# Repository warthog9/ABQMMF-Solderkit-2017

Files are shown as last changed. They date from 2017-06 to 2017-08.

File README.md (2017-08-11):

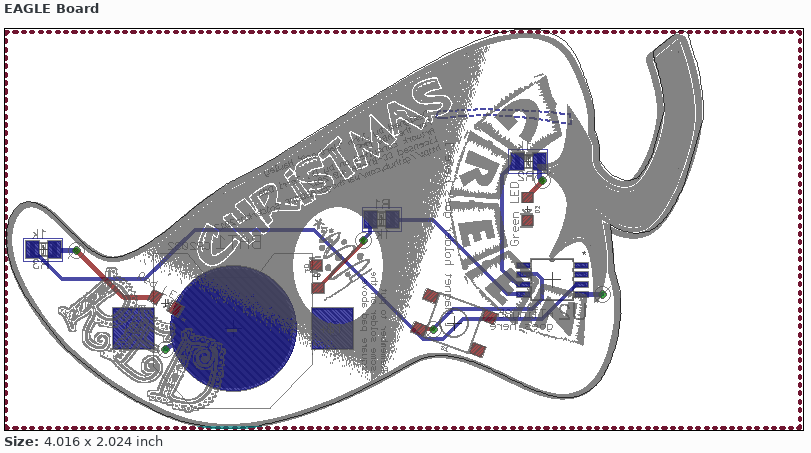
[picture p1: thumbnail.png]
Thumbnail of the Hatch Green Chile Soldering Kit for ABQMMF


This is the learn to solder badge for the Albuquerque Mini Maker Faire.

License:
	The design is opened based on the Creative Commons CC-BY-SA 4.0
	[https://creativecommons.org/licenses/by-sa/4.0/](https://creativecommons.org/licenses/by-sa/4.0/)

	Copyright on the badge is held by John 'Warthog9' Hawley
	
	Copyright to the outline (shape) of the badge is Dr. Terri Oda

	Copyright of the PCBWay Logo is copyright of PCBWay and is used
	with permission specifically for the run of kits used by
	ABQ MMF in 2017

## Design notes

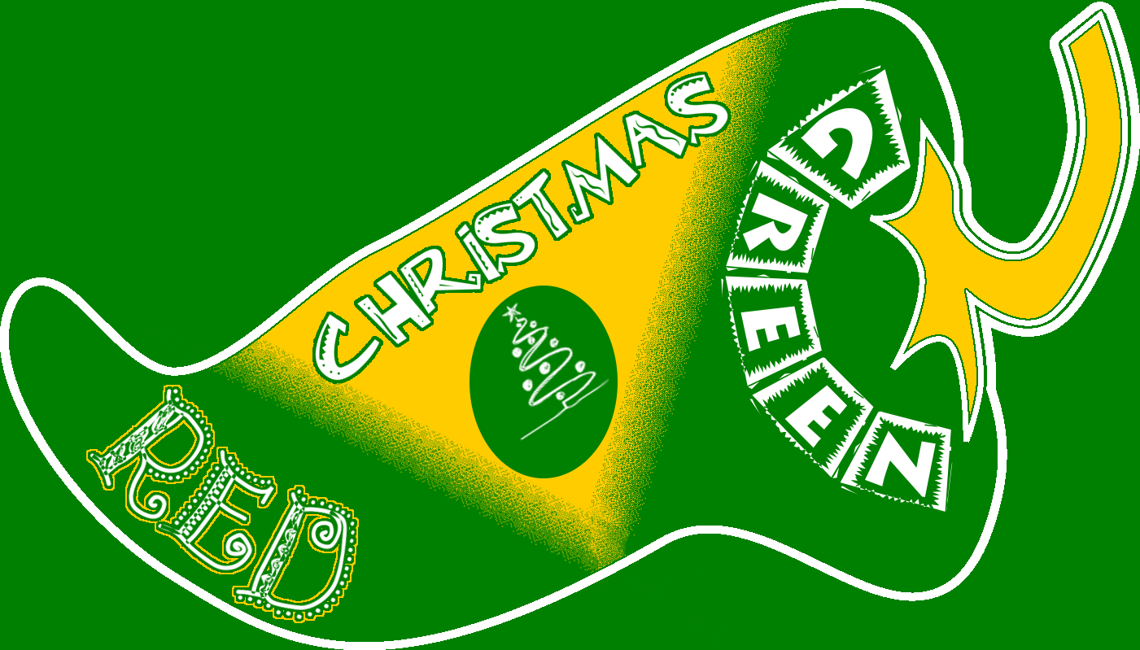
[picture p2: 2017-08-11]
greenchile - w-outline.png

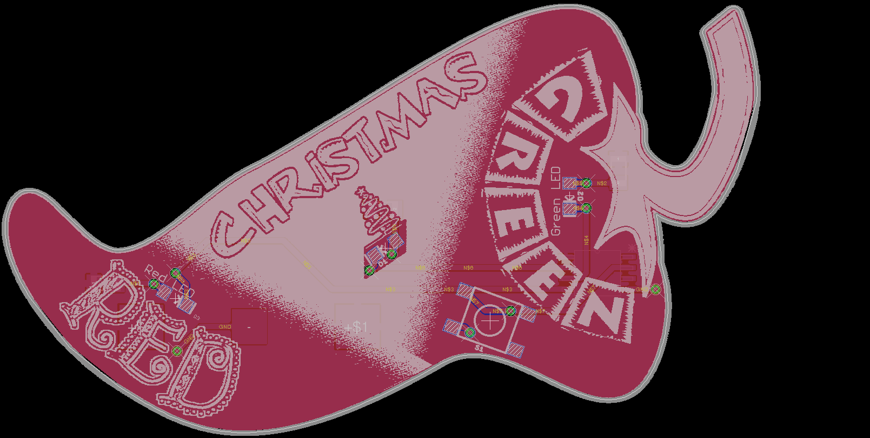
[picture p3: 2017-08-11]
top.png

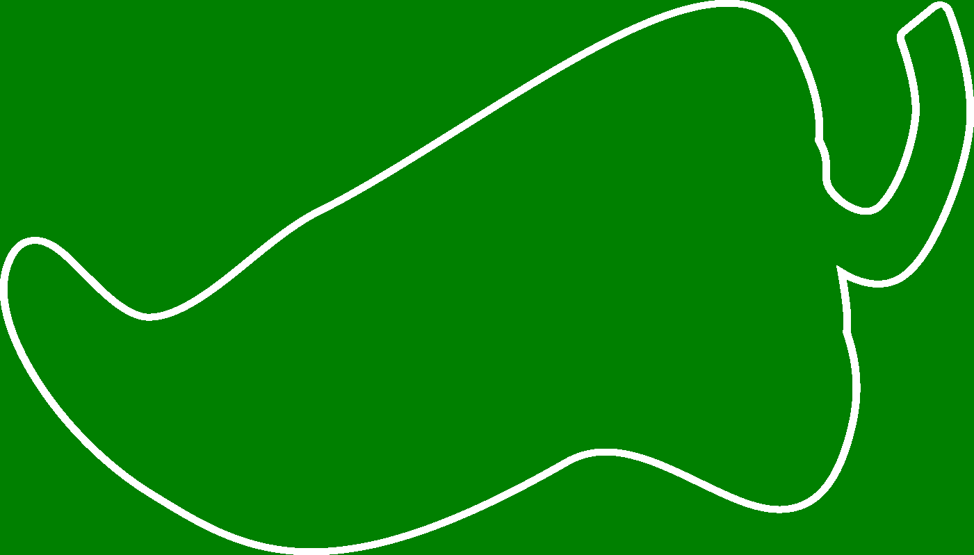
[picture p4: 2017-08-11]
outline.bmp

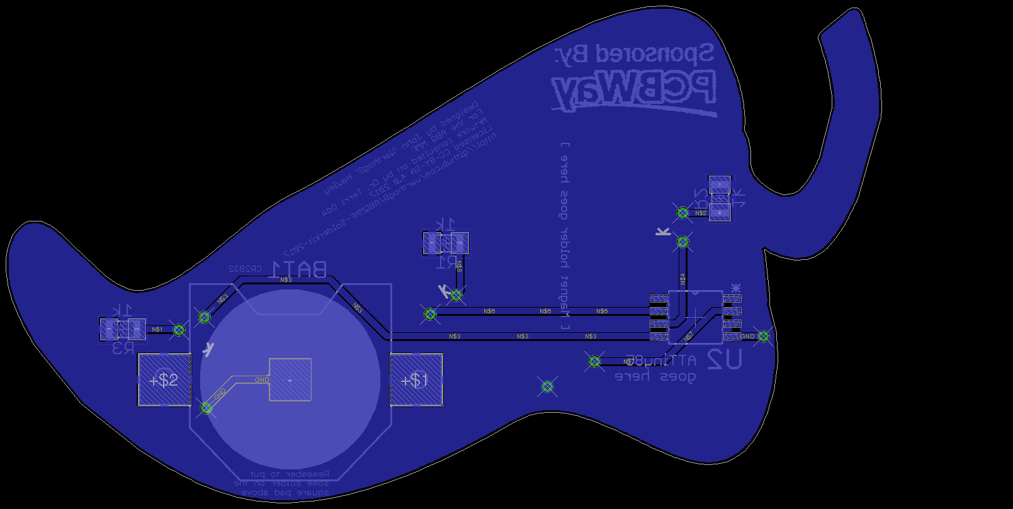
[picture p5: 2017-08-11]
bottom.png

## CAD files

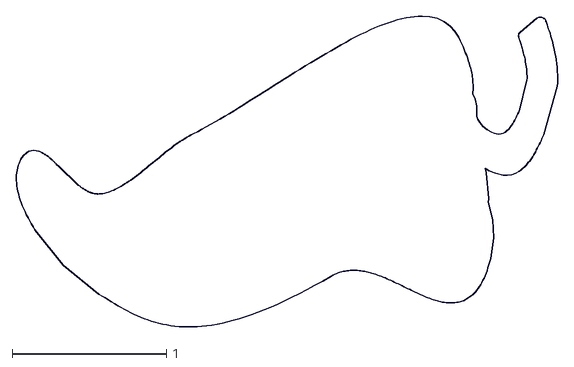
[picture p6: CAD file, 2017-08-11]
greenchile - outline - r9v5.dxf
3.51 x 2.02

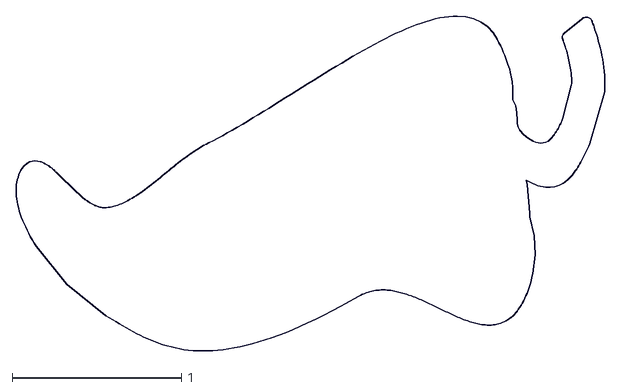
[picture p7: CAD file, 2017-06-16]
greenchile - outline - r9.dxf
3.48 x 1.98

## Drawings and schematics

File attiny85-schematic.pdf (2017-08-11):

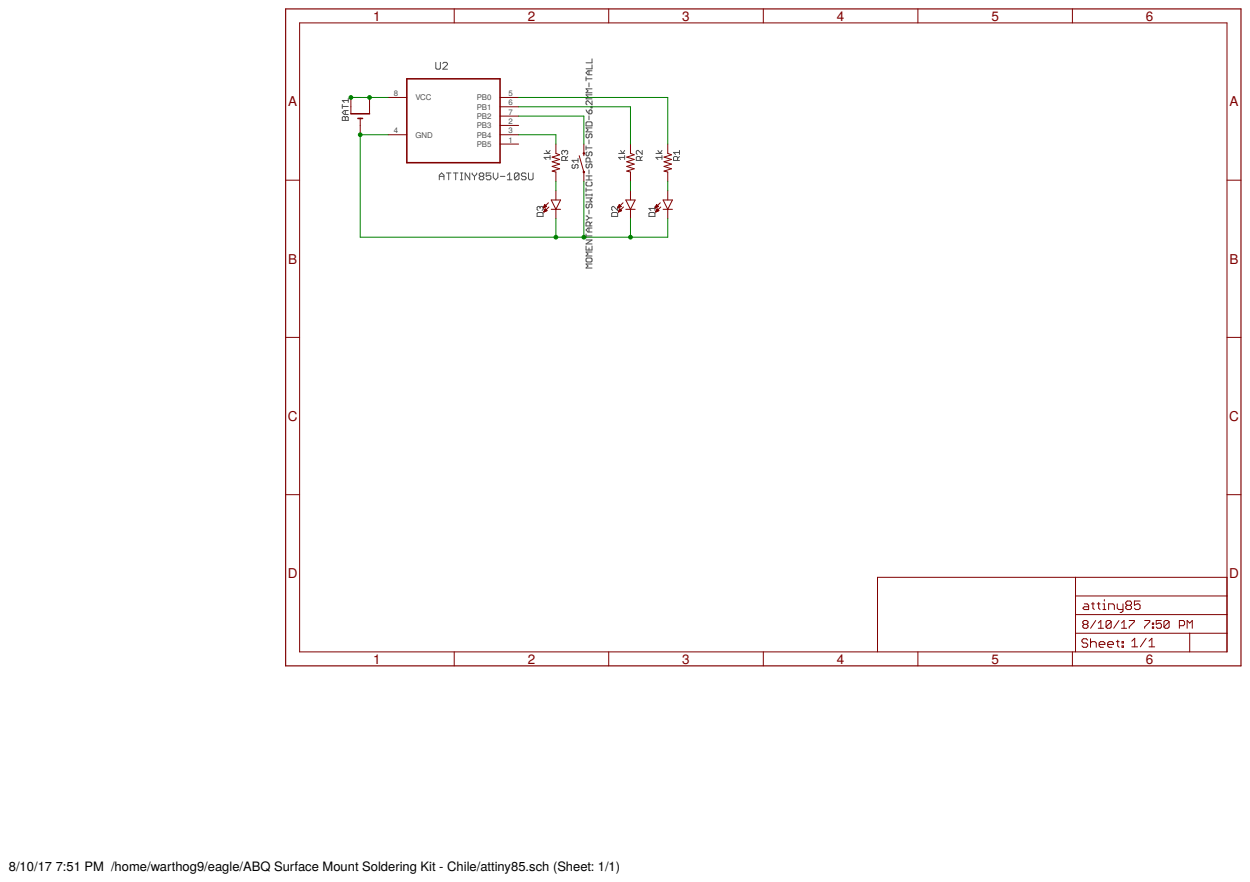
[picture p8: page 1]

8/10/17 7:51 PM /home/warthog9/eagle/ABQ Surface Mount Soldering Kit - Chile/attiny85.sch (Sheet: 1/1)

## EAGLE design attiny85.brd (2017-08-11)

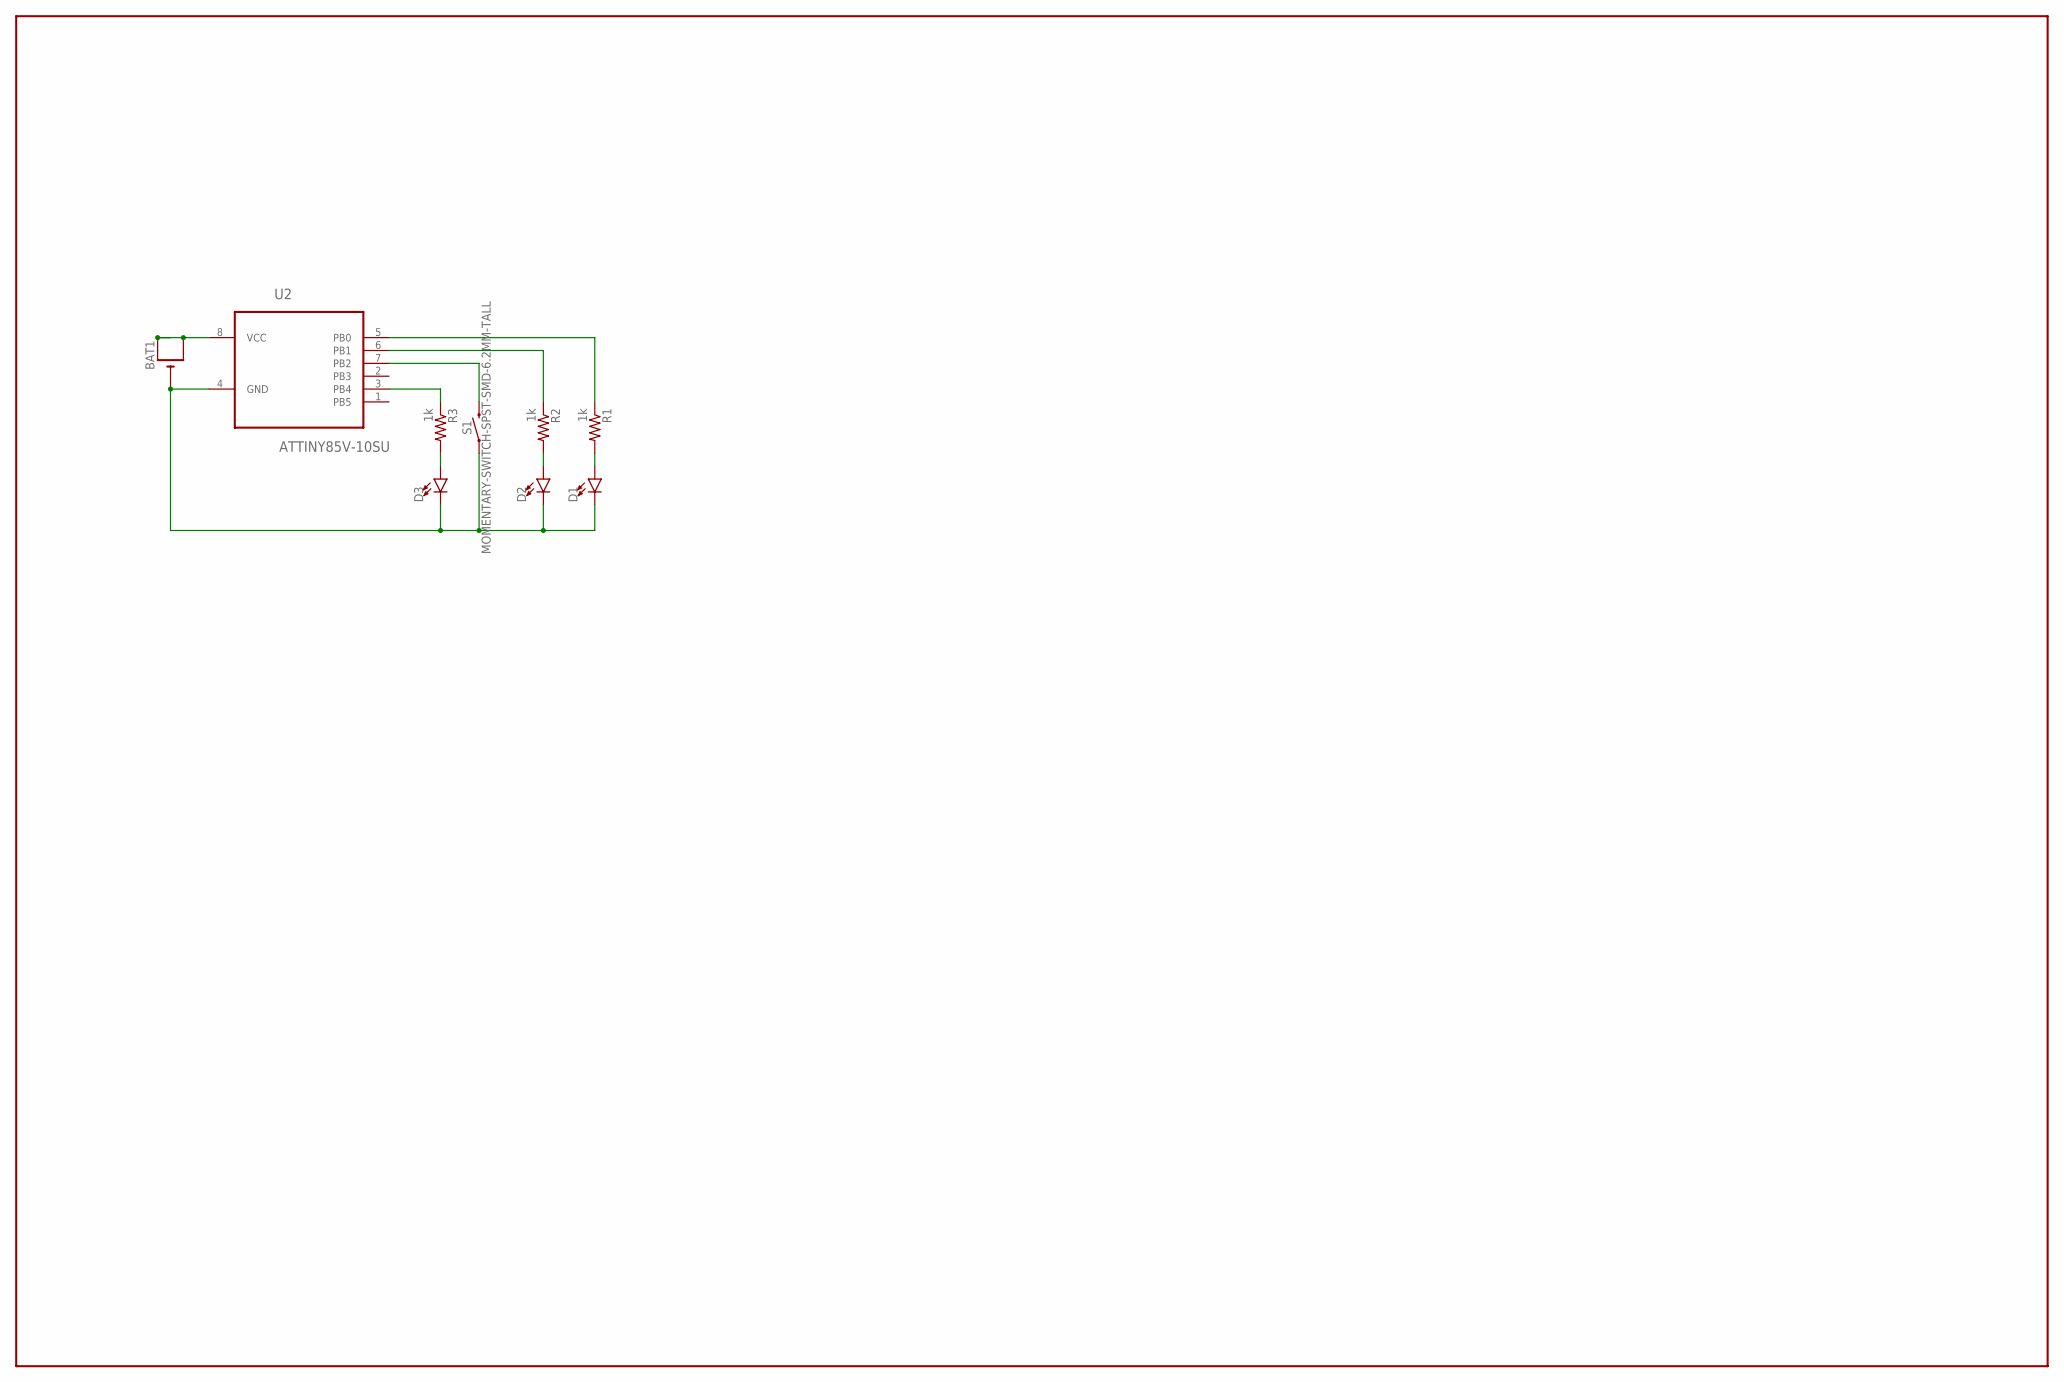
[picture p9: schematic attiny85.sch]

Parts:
BAT1: CR2032SMT; CR2032-SMD
D1, D2, D3: LED1206; LED-1206
R1, R2, R3: 1k; M1206
S1: MOMENTARY-SWITCH-SPST-SMD-6.2MM-TALL; TACTILE_SWITCH_SMD_6.2MM_TALL
U2: ATTINY85V-10SU; SOIC127P798X216-8N

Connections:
GND: BAT1.-, D1.C, D2.C, D3.C, S1.A2 (1), U2.4 (GND)
unnamed: D3.A, R3.2
unnamed: D2.A, R2.2
unnamed: R1.1, U2.5 (PB0)
unnamed: R2.1, U2.6 (PB1)
unnamed: D1.A, R1.2
unnamed: R3.1, U2.3 (PB4)
unnamed: S1.B2 (2), U2.7 (PB2)
VCC: BAT1.+$1 (+), BAT1.+$2 (+1), U2.8 (VCC)

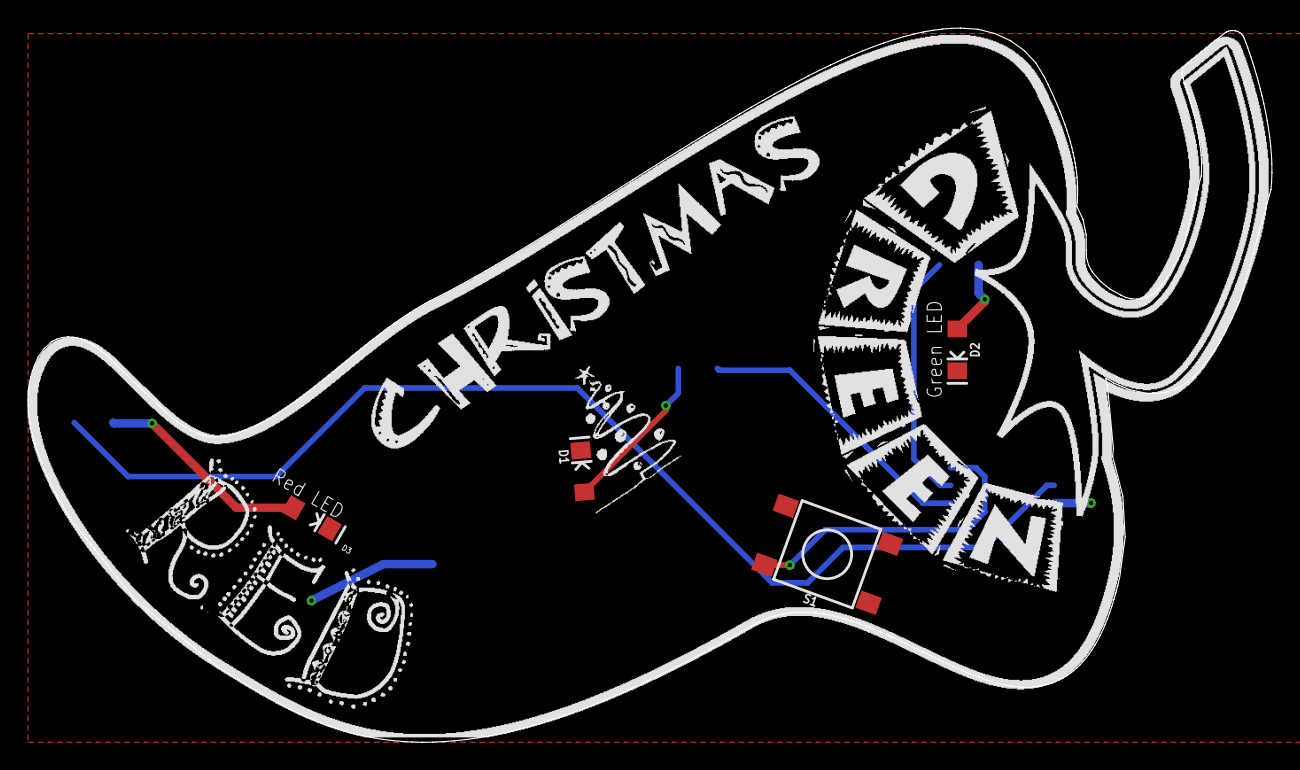
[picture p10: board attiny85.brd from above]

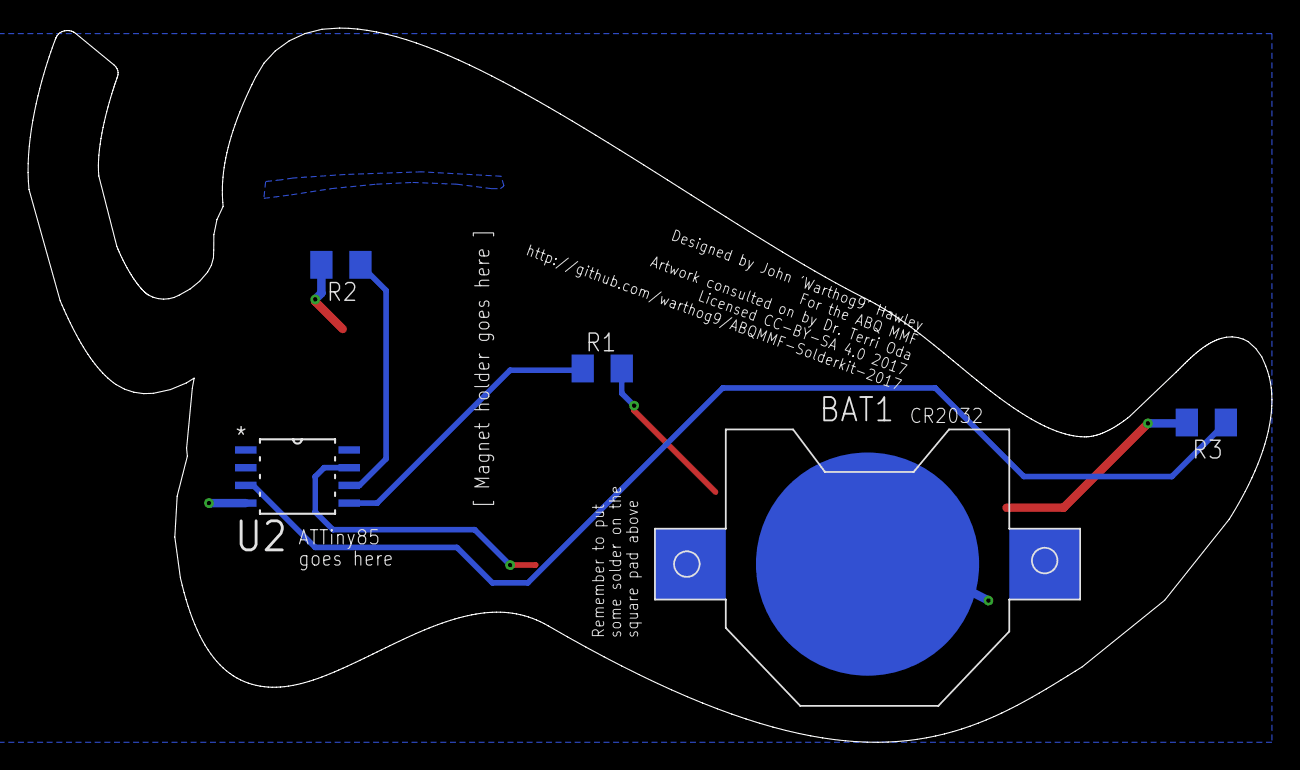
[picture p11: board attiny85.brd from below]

Board: 2 copper layers, 89.2 x 51.2 mm, 9 parts (5 on the bottom side), 9 nets.

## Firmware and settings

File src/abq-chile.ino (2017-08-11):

// This code does work! yay!

int redLEDPin = 1;   // 
int greenLEDPin = 0; // works
int xmasLEDPin = 4;  //
int whatBtn = 2;

int randSeedPin = 3;

int leds[] = { redLEDPin, greenLEDPin, xmasLEDPin };
int numLEDS = 3;

int maxBrightness = 128;

void setup()
{
  int delaytime = 500;
  
  pinMode(redLEDPin, OUTPUT);
  pinMode(greenLEDPin, OUTPUT);
  pinMode(xmasLEDPin, OUTPUT);
  
  pinMode(whatBtn, INPUT_PULLUP);

  //sparkle();

  //pinMode(randSeedPin, INPUT);
  randomSeed(analogRead(randSeedPin));
  
  digitalWrite(redLEDPin, HIGH);   // sets the LED on
  delay(delaytime);                  // waits for a second
  digitalWrite(redLEDPin, LOW);    // sets the LED off
  delay(delaytime);                  // waits for a second
  
  digitalWrite(greenLEDPin, HIGH);   // sets the LED on
  delay(delaytime);                  // waits for a second
  digitalWrite(greenLEDPin, LOW);    // sets the LED off
  delay(delaytime);                  // waits for a second
  
  digitalWrite(xmasLEDPin, HIGH);   // sets the LED on
  delay(delaytime);                  // waits for a second
  digitalWrite(xmasLEDPin, LOW);    // sets the LED off
  delay(delaytime);                  // waits for a second
  
  //attachInterrupt(whatBtn, choose, FALLING);
  
  attachInterrupt(0, choose, FALLING);
  
}

void loop()
{ 
  return;
  
  int x = 0;

  if( digitalRead(whatBtn) == LOW ){
/*
    digitalWrite(redLEDPin, HIGH);   // sets the LED on
    digitalWrite(greenLEDPin, HIGH);   // sets the LED on
    digitalWrite(xmasLEDPin, HIGH);   // sets the LED on
    delay(1000);                  // waits for a second
    digitalWrite(redLEDPin, LOW);   // sets the LED on
    digitalWrite(greenLEDPin, LOW);   // sets the LED on
    digitalWrite(xmasLEDPin, LOW);   // sets the LED on
    delay(1000);                  // waits for a second  

    for( x = 0; x <= 255 ; x++ ){
      analogWrite(redLEDPin, x);
      analogWrite(greenLEDPin, x);
      analogWrite(xmasLEDPin, x);
      delay( 5 );
    }
    
    delay( 200 );
*/
    digitalWrite(redLEDPin, HIGH);
    digitalWrite(greenLEDPin, HIGH);
    digitalWrite(xmasLEDPin, HIGH);
    
    for( x = 255; x >= 0 ; x = x -1 ){
      analogWrite(redLEDPin, x);
      analogWrite(greenLEDPin, x);
      analogWrite(xmasLEDPin, x);
      delay( 5 );
    }
    digitalWrite(redLEDPin, LOW);
    digitalWrite(greenLEDPin, LOW);
    digitalWrite(redLEDPin, LOW);
  }
  
  return; 
}

void choose() { 
  int what = LOW;
  int winner = random( 0, 4 );
  if( winner >= 3 ){
    winner = 0;
  }
  
  clear();
  /*
  for( int x = 0; x < 5; x++ ){
    if( x % 2 != 0 ){
      what = LOW;
    } else {
      what = HIGH;
    }
    
     for( int x = 0; x < numLEDS; x++ ){
      digitalWrite(leds[x], what);
    }
    delay( 5000 );
    

  }*/
  for (int sparkletime  = 2000; sparkletime > 0; sparkletime = sparkletime - 500) 
  {
    for (int i = 0; i < numLEDS; i++) {
      digitalWrite(leds[i], HIGH);
      delay(sparkletime);
      digitalWrite(leds[i], LOW);
      delay(sparkletime);
    }
  }
  
  delay(5000);  
  clear();
  
  digitalWrite( leds[winner], HIGH);
  
  delay( 30000 );
  
  clear();
}

void clear() {
  for( int x = 0; x < numLEDS; x++ ){
    digitalWrite(leds[x], LOW);
  }  
}

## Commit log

2017-01-02 Adding Board Schematic, Layout, & additional files for design
    [attiny85.brd, attiny85.sch, outline.dxf]
2017-05-29 Removing Balloon specific pieces for Chile conversion
    [outline.dxf]
2017-06-16 Initial Artwork commit
    [greenchile - outline - r9.dxf]
2017-06-16 Updated schematic and layout for surface mount components
    [attiny85.brd, attiny85.sch]
2017-08-11 Moving R3 to be more accessible
    [attiny85.brd]
2017-08-11 Moving the notice about the solder dob
    [attiny85.brd]
2017-08-11 Increase font size of CR2032, and info
    [attiny85.brd]
2017-08-11 Flipping to output through the attiny
    [attiny85.brd, attiny85.sch]
2017-08-11 Updating pads and rerouting
    [attiny85.brd, attiny85.sch]
2017-08-11 Adding in new outline dxf
    [greenchile - outline - r9v5.dxf]
2017-08-11 Updating the board and schematic
    This is a fairly big set of changes based on the prototype, going
    to run another round just to be sure since I've got enough time.
    [attiny85.brd, attiny85.sch]
2017-08-11 Switching to using the "3" PWMs for the LEDs
    [attiny85.brd, attiny85.sch]
2017-08-11 Using a smaller frame on the schematic
    [attiny85.sch]
2017-08-11 Adding the schematic
2017-08-11 Adding Arduino Source Code + hex output
    This requires that you have the Arduino board information from
    https://github.com/damellis/attiny
    which is more easily consumed from Sparkfun's site here:
    https://cdn.sparkfun.com/assets/learn_tutorials/1/5/0/attiny-ide-1.6.x.zip
    an entire tutorial on how to set this up can be found here:
    https://learn.sparkfun.com/tutorials/tiny-avr-programmer-hookup-guide
    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
2017-08-11 Adding latest gerbers
    [attiny85.drills.xln]

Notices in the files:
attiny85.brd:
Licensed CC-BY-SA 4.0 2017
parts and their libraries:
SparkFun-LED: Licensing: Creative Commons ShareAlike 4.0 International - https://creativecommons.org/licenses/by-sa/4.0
